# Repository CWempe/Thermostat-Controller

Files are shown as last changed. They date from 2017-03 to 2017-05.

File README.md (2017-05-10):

# Thermostat-Controller

This Project improves the **Junkers TRQ 21 T** Thermostat with the following features:

* mute the ticking clock  
  By disconnecting the timer clock from the thermostat the clock will stop ticking eventually  
  (might take a few weeks before the battery dies)
* support weekends  
  The default timer clock does not differentiate between work days and weekends  
  By controlling the thermostat with your smart home, you can define every timer rule you want
* support presence detection and geo location  
  If your smart home supports it, your thermostat will do too now
* support disabling when windows are open  
  If your smart home supports it, ...

Best of all: Your thermostat will not be managed and you can still change to day and night mode manually like before.

## How does it work

You will replace the internal timer clock with an Arduino (esp8266) to switch between day and night mode.  
The Arduino will be connected via WiFi and communicates via [mqtt](http://mqtt.org/) with your smart home (e.g. [openHAB](http://www.openhab.org/)).  
You can optionally integrate a button to change the current mode without switching to manual mode on the thermostat. But this may require damaging the original case if want it to look good.

## What you need

Beside some standard components, you need:  

* **Arduino**: Wemos D1 mini (pro)  
  [Website](https://www.wemos.cc/product/d1-mini-pro.html)  
* **Relay**: Panasonic DS2Y-5-DC5V  
  [Datasheet](https://www3.panasonic.biz/ac/e_download/control/relay/signal/catalog/mech_eng_ds2y.pdf)
* **DC-DC Converter**: Recom R-78B5.0-1.0L  
  [Website](https://www.recom-power.com/de/emea/home.html)  
  [Datasheet]([https://www.recom-power.com/pdf/Innoline/R-78Bxx-1.0_L.pdf)
* **Temp sensor**: Dallas DS18B20  
  [Website](https://www.maximintegrated.com/en/products/analog/sensors-and-sensor-interface/DS18B20.html)  
  [Datasheet](https://datasheets.maximintegrated.com/en/ds/DS18B20.pdf)  
* **Wire-to-Board connector**  
 *  molex SPOX™ Wire-to-Board Crimp Housing  
  2.50mm Pitch SPOX™ Wire-to-Board Crimp Housing, Friction Lock, 5 Circuits  
  [Website](http://www.molex.com/molex/products/datasheet.jsp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)  
  [Datasheet](http://www.molex.com/webdocs/datasheets/pdf/en-us/0050375053_CRIMP_HOUSINGS.pdf)  
 * molex SPOX™ BMI Connector System (5x)  
  2.50mm Pitch SPOX™ Crimp Terminal, 22-28 AWG, Bag  
  [Website](http://www.molex.com/molex/products/datasheet.jsp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)  
  [Datasheet](http://www.molex.com/webdocs/datasheets/pdf/en-us/0008701040_CRIMP_TERMINALS.pdf)
  
## Photos

### Thermostat

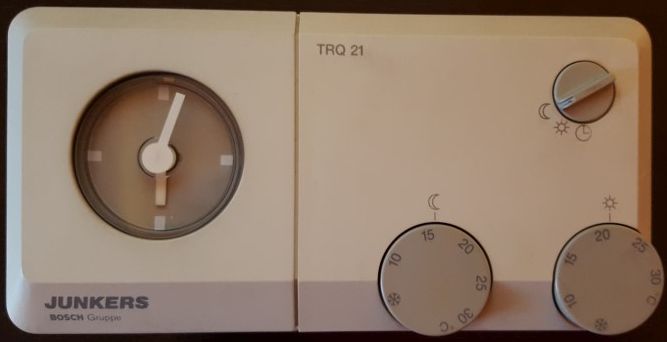
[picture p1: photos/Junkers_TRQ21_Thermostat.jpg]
thermostat


### timer clock

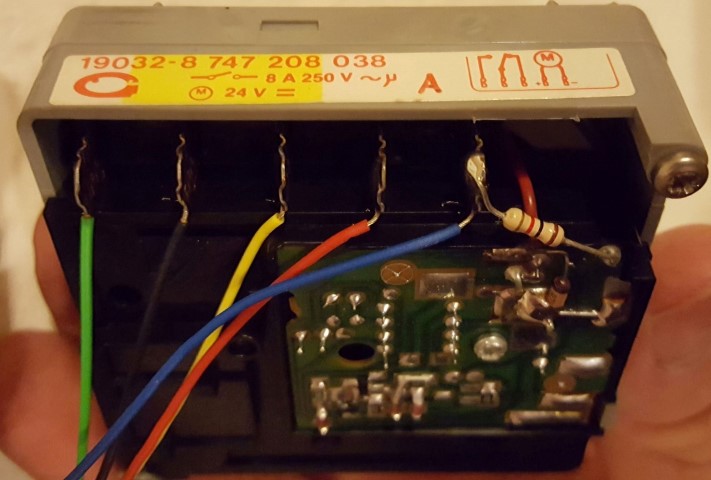
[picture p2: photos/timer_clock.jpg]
timer_clock


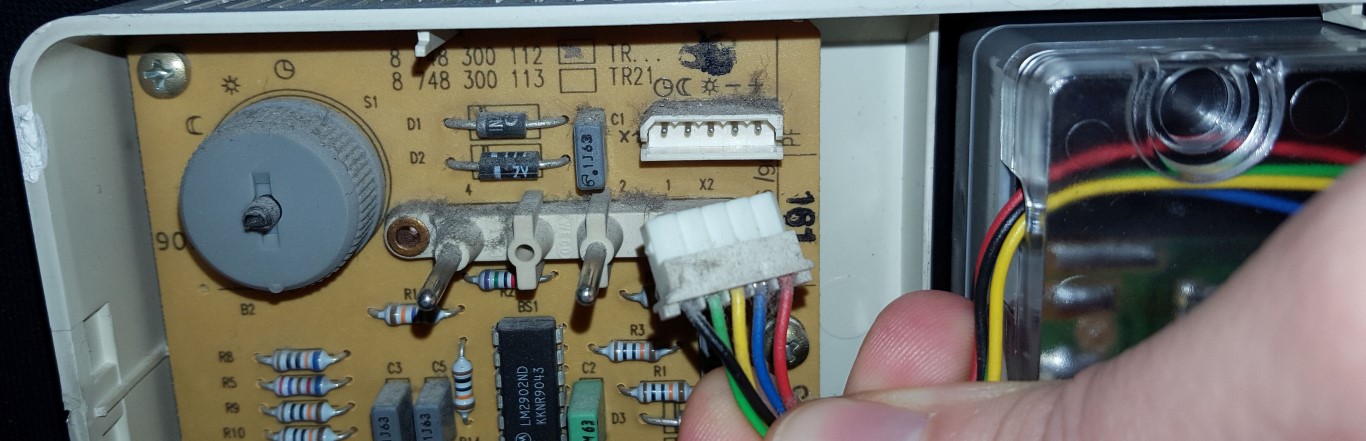
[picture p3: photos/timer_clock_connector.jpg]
timer_clock_connector


## Circiut Diagram
  
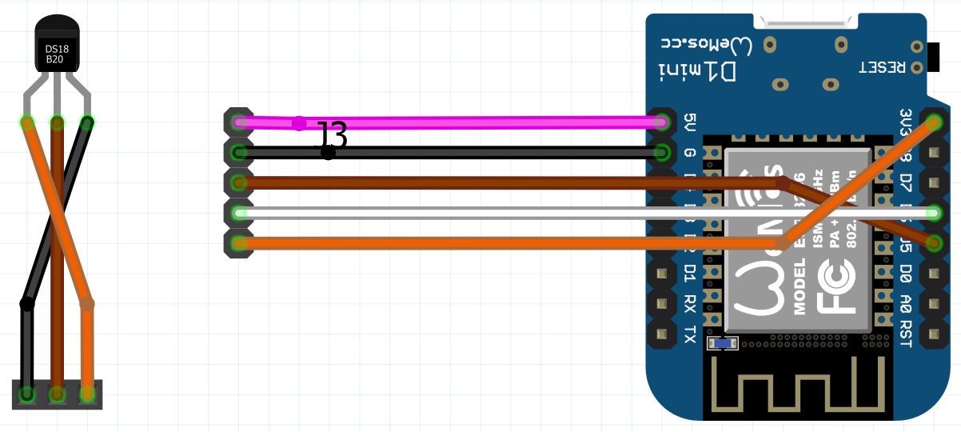
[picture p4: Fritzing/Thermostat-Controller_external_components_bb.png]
ext_comopnents


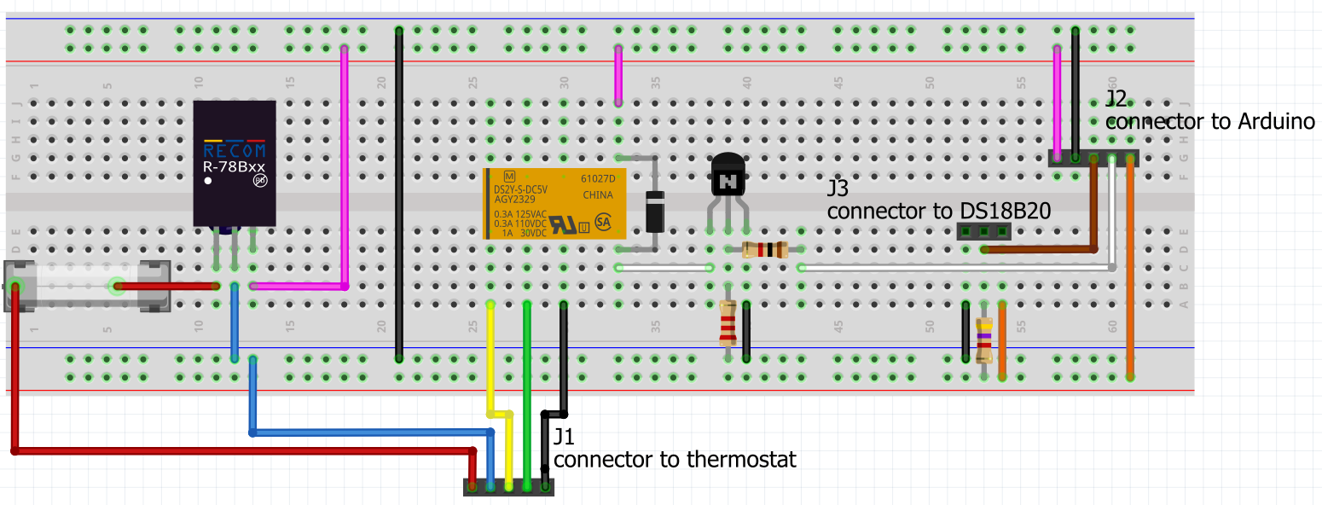
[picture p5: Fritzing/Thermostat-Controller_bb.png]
breakboard


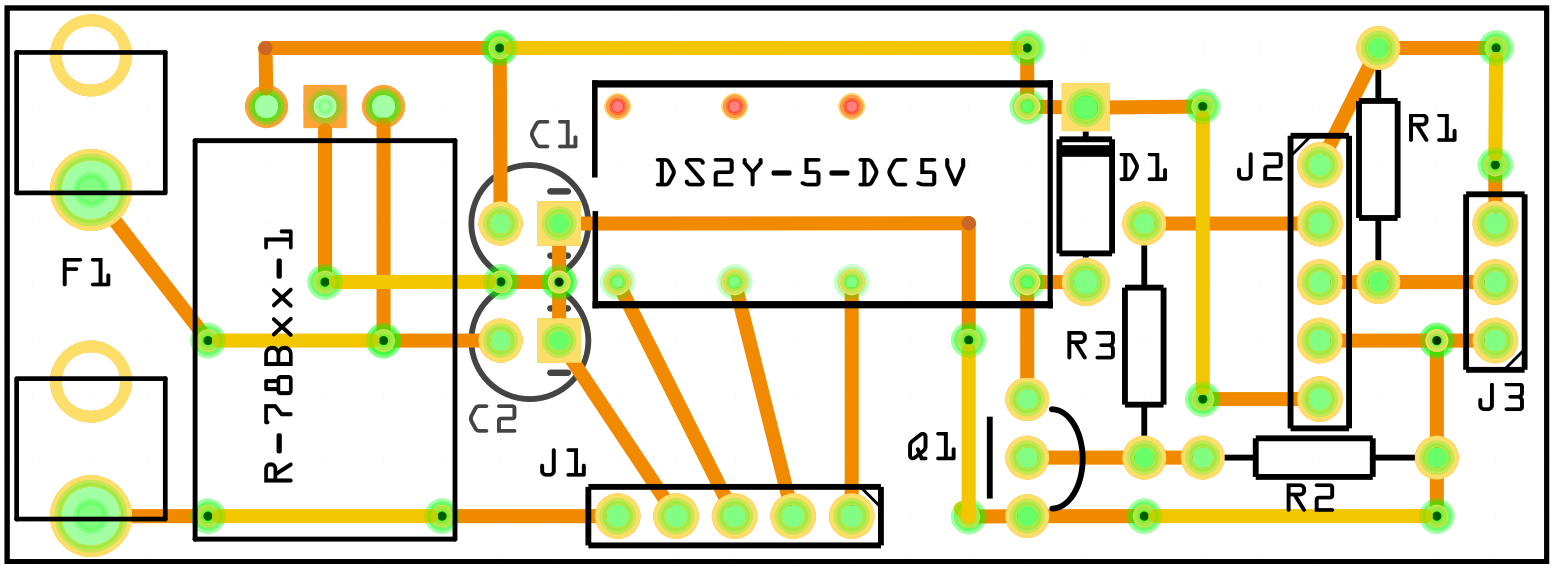
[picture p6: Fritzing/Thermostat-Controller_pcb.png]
pcb


## Photos

You can find more photos of the finished project in the photos directory.

## configure Arduino (Sonoff-Tasmota)

Open the web interface of your controller.  
Click `Configuration` and then `Configure Mode`. Select the `Module Type`.  
Here : "18 Wemos D1 mini".

Define the Sensors for the GPIOs.

* GPIO12: "17 Relay1"
* GPIO13: "09 Switch1" (optional, if you add a switch to the project)
* GPIO14: "04 DS18x20"

Click `Save`

If you added a switch to your project, execute the following commands in the `Console` in the web interface.

```
SwitchMode1 2
SwitchTopic1 wemos01-switch
```

See [this page](https://github.com/arendst/Sonoff-Tasmota/wiki/Understanding-SwitchMode-and-SwitchTopic) for more details.

## configure openhab

You can find some example configuration files in the openhab folder.

You basically need an item for the relay and an item for the temperature sensor.
To make use of some smart automation rules and manual override you might want to configure some virtual items.
If you have any windows or door contacts connected to your smart home you also might want to turn the thermostat off while you let some fresh air in.

You can also use a transformation file to display more accurate terms than "ON" and "OFF" for day and night mode.

Finally I renamed some openhab2 classic icons to thermostat*.png/svg. (see /openhab/icons)

### Example (openHAB)
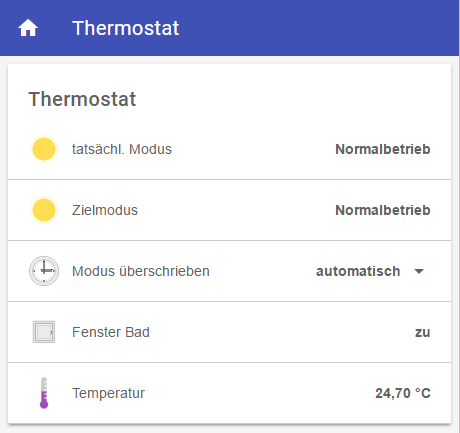
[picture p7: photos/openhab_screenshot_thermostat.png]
openhab_screenshot
  
The current mode is "Nachtabsenkung" (night mode)
The target mode is set to "Normalbetrieb" (day mode).  
The override mode is set to "automatic" (this means no override).  
The window is open.  

While the current mode should be "day mode", because of the target mode, it actually is "night mode", because the window is open.
Once the window closes the mode changes to "day mode" (target mode).

[ext_comopnents]: Fritzing/Thermostat-Controller_external_components_bb.png "external components"
[breakboard]: Fritzing/Thermostat-Controller_bb.png "breakboard view"
[pcb]: Fritzing/Thermostat-Controller_pcb.png "pcb view"
[thermostat]: photos/Junkers_TRQ21_Thermostat.jpg
[timer_clock]: photos/timer_clock.jpg
[timer_clock_connector]: photos/timer_clock_connector.jpg
[openhab_screenshot]: photos/openhab_screenshot_thermostat.png

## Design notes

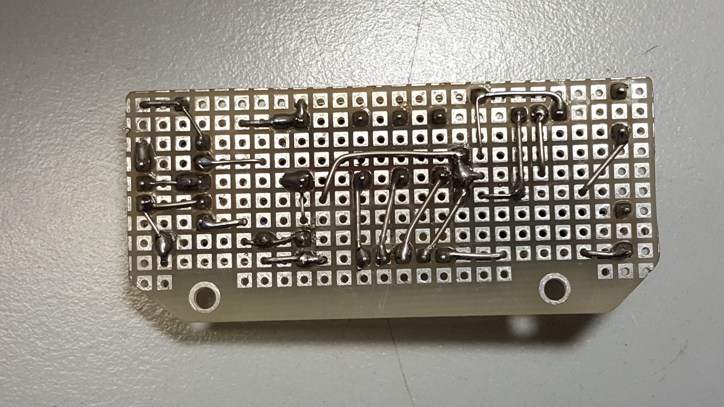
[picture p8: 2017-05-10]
photos/photo_pcb_bottom.jpg

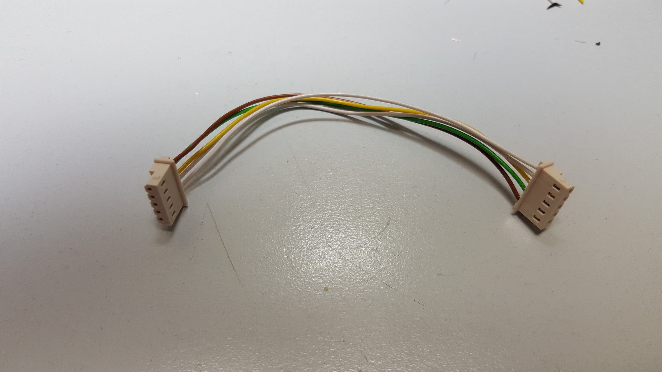
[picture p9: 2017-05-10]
photos/photo_connector_cable.jpg

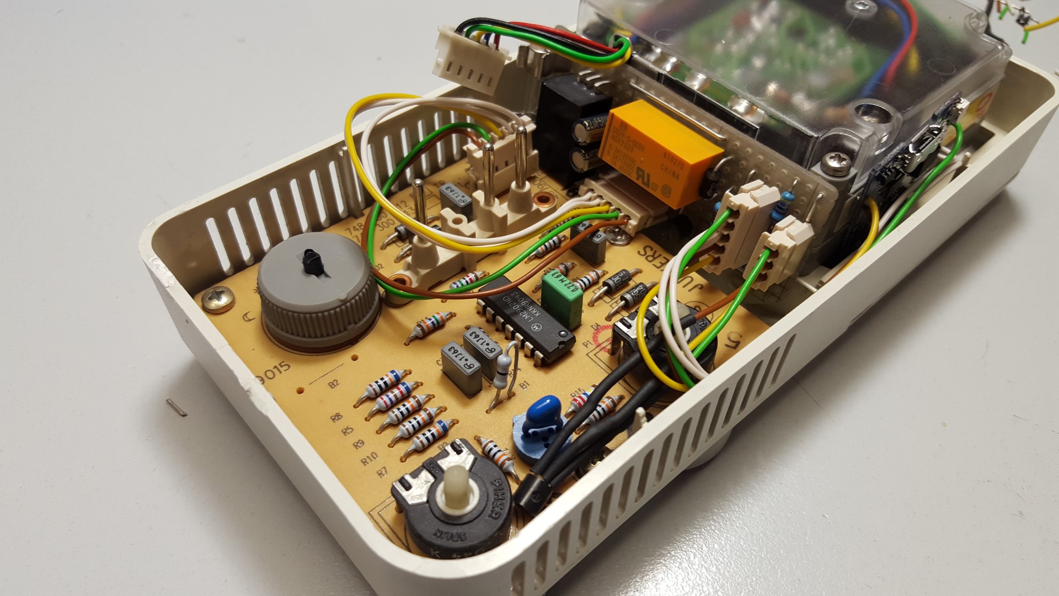
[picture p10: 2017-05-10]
photos/photo_thermostat_with_controller.jpg

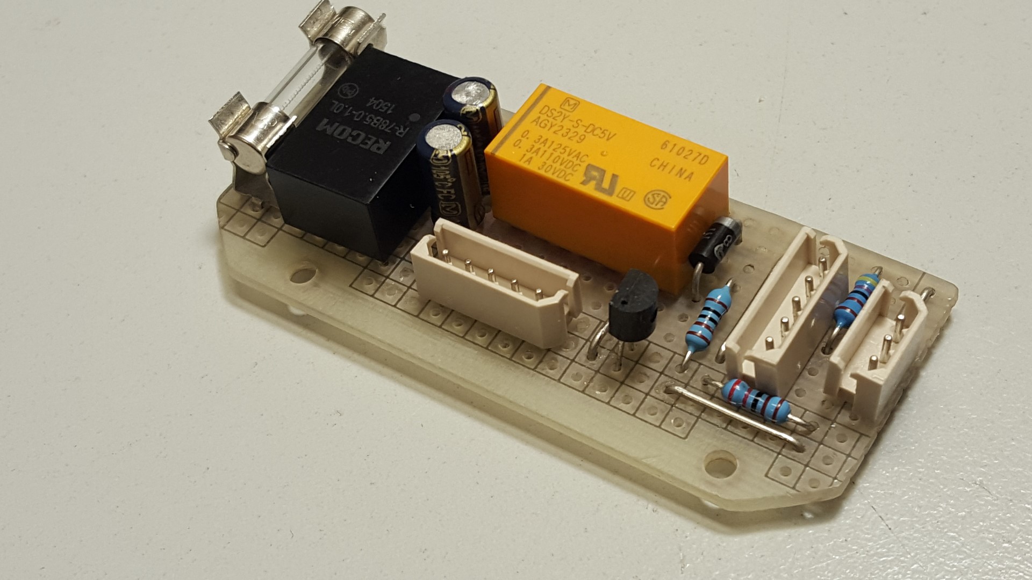
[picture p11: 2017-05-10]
photos/photo_pcb_isometric_view.jpg

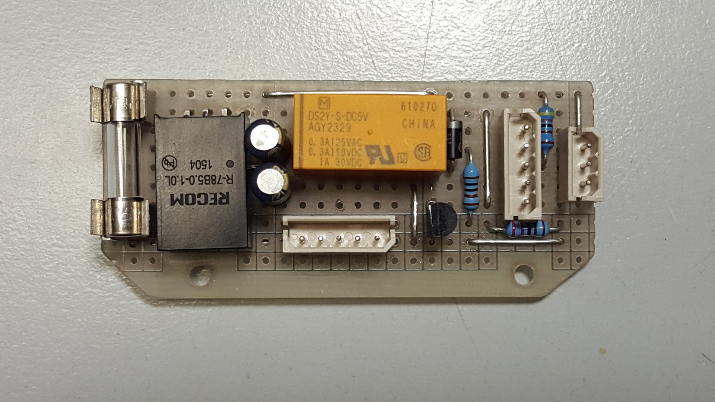
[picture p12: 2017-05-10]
photos/photo_pcb_top.jpg

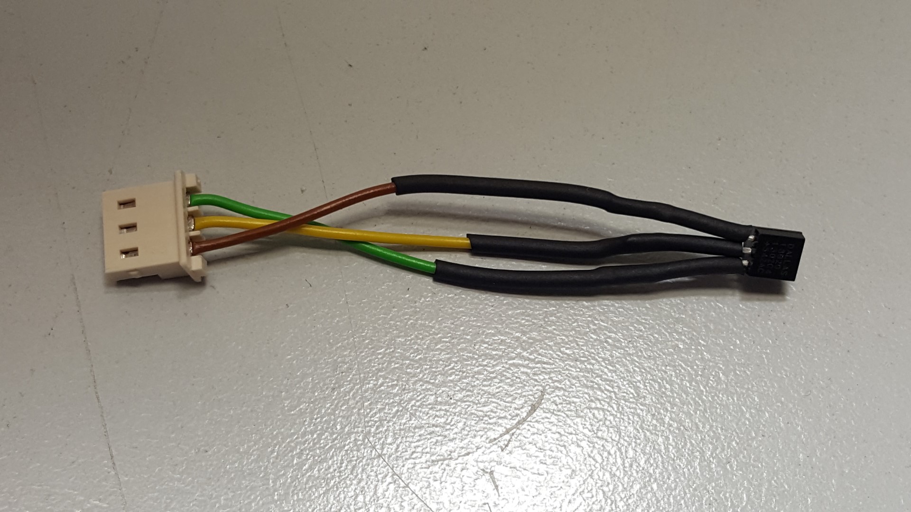
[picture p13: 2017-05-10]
photos/photo_temp_with_cable.jpg

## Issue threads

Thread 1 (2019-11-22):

Part List

rj-dot, 2019-11-22:
Dear CWempe,

can you help me with the parts list?
I try to buy the parts at Conrad.de

Some of the parts aren't listed, the resistance i can see on the picture but the product specification from the other parts not, i would appreciate if you help me at this point.

https://www.conrad.de/de/p/recom-r-78b5-0-1-0l-dc-dc-wandler-print-32-v-dc-5-v-dc-1-a-5-w-anzahl-ausgaenge-1-x-676147.html
https://www.conrad.de/de/p/panasonic-ds2ys5-printrelais-5-v-dc-2-a-2-wechsler-1-st-504944.html
https://www.conrad.de/de/p/joy-it-temperatursensor-ds18b20-1wire-1695377.html

Best regards,
Rico

CWempe, 2019-11-22:
I would recommend to buy the **DS18B20** from ebay.de.
You can find a package of 5 pieces for about 6€.
Conrad is rather expensive with these little parts.

This is what I bought:
* https://www.ebay.de/itm/5x-DS18B20-Digitaler-Temperaturfuhler-Temperatursensor-1-wire-Raspberry-Arduino/252713797995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
* https://www.conrad.de/de/p/panasonic-ds2ys5-printrelais-5-v-dc-2-a-2-wechsler-1-st-504944.html
* https://www.conrad.de/de/p/dc-dc-wandler-mean-well-scw05b-05-1000-ma-1297244.html
* https://www.conrad.de/de/p/mpe-garry-buchsenleiste-praezision-anzahl-reihen-1-polzahl-je-reihe-5-115-1-005-0-mtf-xs0-1-st-732331.html
* https://www.conrad.de/de/p/diotec-si-gleichrichterdiode-1n4007-do-204al-1000-v-1-a-162272.html
* https://www.reichelt.de/molex-crimpgehaeuse-mini-spox-1x5-polig-buchse-molex-50375053-p186241.html?
* https://www.reichelt.de/molex-crimpkontakt-mini-spox-buchse-molex-8701040-p185737.html?
* I don't know where I bought the "molex SPOX™ Wire-to-Board Crimp Housing" from. 😐

❗️ WARNING: My gas heating is making strange noises sometimes.
I guess it has an issue with starting the flame.
I don't know if this issue is related to this project.
But otherwise it is working fine with this setup for the last two years. 😃

peerb, 2020-05-05:
Is the warning still standing regarding this solution? I'd like to build it and connect it to the heating system?

CWempe, 2020-05-05:
The warning still stands.
I did not try to find the cause and it still happens sometimes.

But I do not see any other issue.
The device is heating my water wehen ever it should.
It just might take a few tries to start the flame (or wherever the noises come from).

And you can always just plug the original timer back in if you experience the same noises or feel uncomfortable with this solution.

That said: Do at your own risk!

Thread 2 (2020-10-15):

[Q] Alternative Hardware

mdaser, 2020-10-15:
Hello CWempe,
thanks for the detailed instructions and hints to make the TRQ 21 T smarter and connect it to an MQTT server.

As far as I understood, the relay in your solution  switches the black connector on J1 either to green or yellow on J1; being connected to green if the relay is in idle.

I was wondering, whether I could used a device like this:
https://circuit.rocks/relay-esp8266-10a-220v-network-wifi-module-input-dc-7v-30v.html

It may be powered with the 24V of the thermostat (it accepts 7 - 30V) and run something like Tasmota to connect to an MQTT server.
The MQTT server implements the logic, when switching on or off (or rather from day to night mode and vice versa).

Does that sound reasonable?

Thanks in advance!
     Martin

CWempe, 2020-10-17:
I think this should work. (NO GARANTEE!!).

But I am not sure if the board will fit in the thermostat.

Here is a photo from my setup.
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
I build my board to fit exactly between the clock and the original pcb.
The Wemos is places under the clock (right side of the photo).

I guess you would have to remove the clock.

tom2199, 2021-01-11:
@mdaser did you try to build this project with the device in question? Did it work? An update would be awesome, thanks in advance.

tom2199, 2021-01-20:
So I can confirm that this project works with this module (commonly known as Yunshan Relay Module, Tasmota even has built in support for it). @CWempe You are right the module is too big to fit without removing the clock, so it had to go. Below are a few pictures of my setup, I used the easiest solution I came up with, I just glued two layers of cardboard together and screwed the module down on it, the cardboard is held in place by the case.
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

Closed 2021-01-20.

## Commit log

2017-03-22 Sketch: Wemos with DS18B20
    [Thermostat-Controller.fzz]
2017-03-22 add Relay
    [Thermostat-Controller.fzz]
2017-03-22 add contact
    [Thermostat-Controller.fzz]
2017-03-22 optimzed curcit
    [Thermostat-Controller.fzz]
2017-03-22 change format to fz
    [Thermostat-Controller.fz]
2017-03-22 remove fzz file
    [Thermostat-Controller.fzz]
2017-03-22 fix overlapping GND ćable
    [Thermostat-Controller.fz]
2017-03-22 add folder Arduino
2017-03-22 add folder Arduino/portable
2017-03-22 initial README with switch config
2017-03-25 change relay to generic part
    [Thermostat-Controller.fz]
2017-03-25 add custom part DS2Y-5-DC5V
    [Thermostat-Controller.fz]
2017-03-25 change femail pin header to 5 pin
    [Thermostat-Controller.fz]
2017-03-25 change connector colors
    [Thermostat-Controller.fz]
2017-03-25 add step-down converter
    [Thermostat-Controller.fz]
2017-03-25 optimize arrangement
    [Thermostat-Controller.fz]
2017-03-25 revert femaile pin header for better cable layout
    [Thermostat-Controller.fz]
2017-03-25 remove button
    [Thermostat-Controller.fz]
2017-03-25 add temp sensor to README
2017-03-25 Revert "remove button"
    This reverts commit d4ec1047861b43c1adf3036a0edf9753fed9304e.
    [Thermostat-Controller.fz]
2017-03-25 fix cable color
    [Thermostat-Controller.fz]
2017-03-27 replaced generic parts with originals
    [Thermostat-Controller.fz]
2017-03-27 update optimize breakboard
    [Thermostat-Controller.fz]
2017-03-27 fix wrong color for D5 cable
    [Thermostat-Controller.fz]
2017-03-27 move Fritzing files to separate folder
    [Thermostat-Controller.fz]
2017-03-27 add photos of timer clock
2017-03-27 update part icon DS2Y-5-DC5V
    [Thermostat-Controller.fz]
2017-03-31 interchange yellow and green cable
    [Thermostat-Controller.fz]
2017-03-31 add molex connector to parts list
2017-03-31 remove yellow bendpoint
    [Thermostat-Controller.fz]
2017-04-01 resize timer_clock.jpg smaller
2017-04-01 remove switch from breadboard
    [Thermostat-Controller.fz]
2017-04-01 remove switch from README
2017-04-01 fix pcb of fritzing part SCW05B-05
    [Thermostat-Controller.fz]
2017-04-02 redesign breadboard and pcb
    [Thermostat-Controller.fz]
2017-04-13 replace converter with voltage regulator
    [Thermostat-Controller.fz]
2017-04-13 move board to center
    [Thermostat-Controller.fz]
2017-04-13 optimize wires
    [Thermostat-Controller.fz]
2017-04-13 add connector between Wemos and board
    [Thermostat-Controller.fz]
2017-04-14 redo pcb layout
    [Thermostat-Controller.fz]
2017-04-18 fix wrong size of DS2Y-5-DC5V pcb
    [Thermostat-Controller.fz]
2017-04-21 add small step down converter to Fritzing
    [Thermostat-Controller.fz]
2017-04-23 replaced 78xx with R-78Bxx
    [Thermostat-Controller.fz]
2017-04-23 update images
    [Thermostat-Controller.fz]
2017-04-23 moved R-78Bxx 1 pin down
    [Thermostat-Controller.fz]
2017-04-23 changed position of converter and fuse
    [Thermostat-Controller.fz]
2017-04-23 changed position of converter and fuse back again
    [Thermostat-Controller.fz]
2017-05-04 change and correct capacitors
    [Thermostat-Controller.fz]
2017-05-07 add connector an resistor for DS18B20 on pcb
    [Thermostat-Controller.fz]
2017-05-07 move C4 1 pin down
    [Thermostat-Controller.fz]
2017-05-08 optimize pcb to save one line in hight
    [Thermostat-Controller.fz]
2017-05-08 optimize pcb after physical testing
    [Thermostat-Controller.fz]
2017-05-08 change parts from smd to tht and optimize layout
    [Thermostat-Controller.fz]
2017-05-08 optimize routing
    [Thermostat-Controller.fz]
2017-05-08 split external components in separat fritzing file
    [Thermostat-Controller.fz, Thermostat-Controller_external_components.fz]
2017-05-08 update PNGs and rearange breadboard
    [Thermostat-Controller.fz]
2017-05-10 add missing GND route
    [Thermostat-Controller.fz]
2017-05-10 optimize lables in bb view
    [Thermostat-Controller.fz]
2017-05-10 rewire external components to reflect actual wiring
    [Thermostat-Controller_external_components.fz]
